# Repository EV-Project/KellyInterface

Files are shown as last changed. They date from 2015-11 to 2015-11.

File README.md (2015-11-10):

# KellyInterface
A hardware interface to link the Kelly motor controller to a CAN bus control scheme
This uses a digital Potentiometer to drive the throttle and brake signals, and BJTs to drive the microswitch inputs.

Includes a CAN and RS232 interface between the Kelly motor controller and a teensy3.2.
Also features a configurable E-stop line and hardware shutdown signal, RC charge-pump Watchdog timer, and access to the motor's hall effect outputs.

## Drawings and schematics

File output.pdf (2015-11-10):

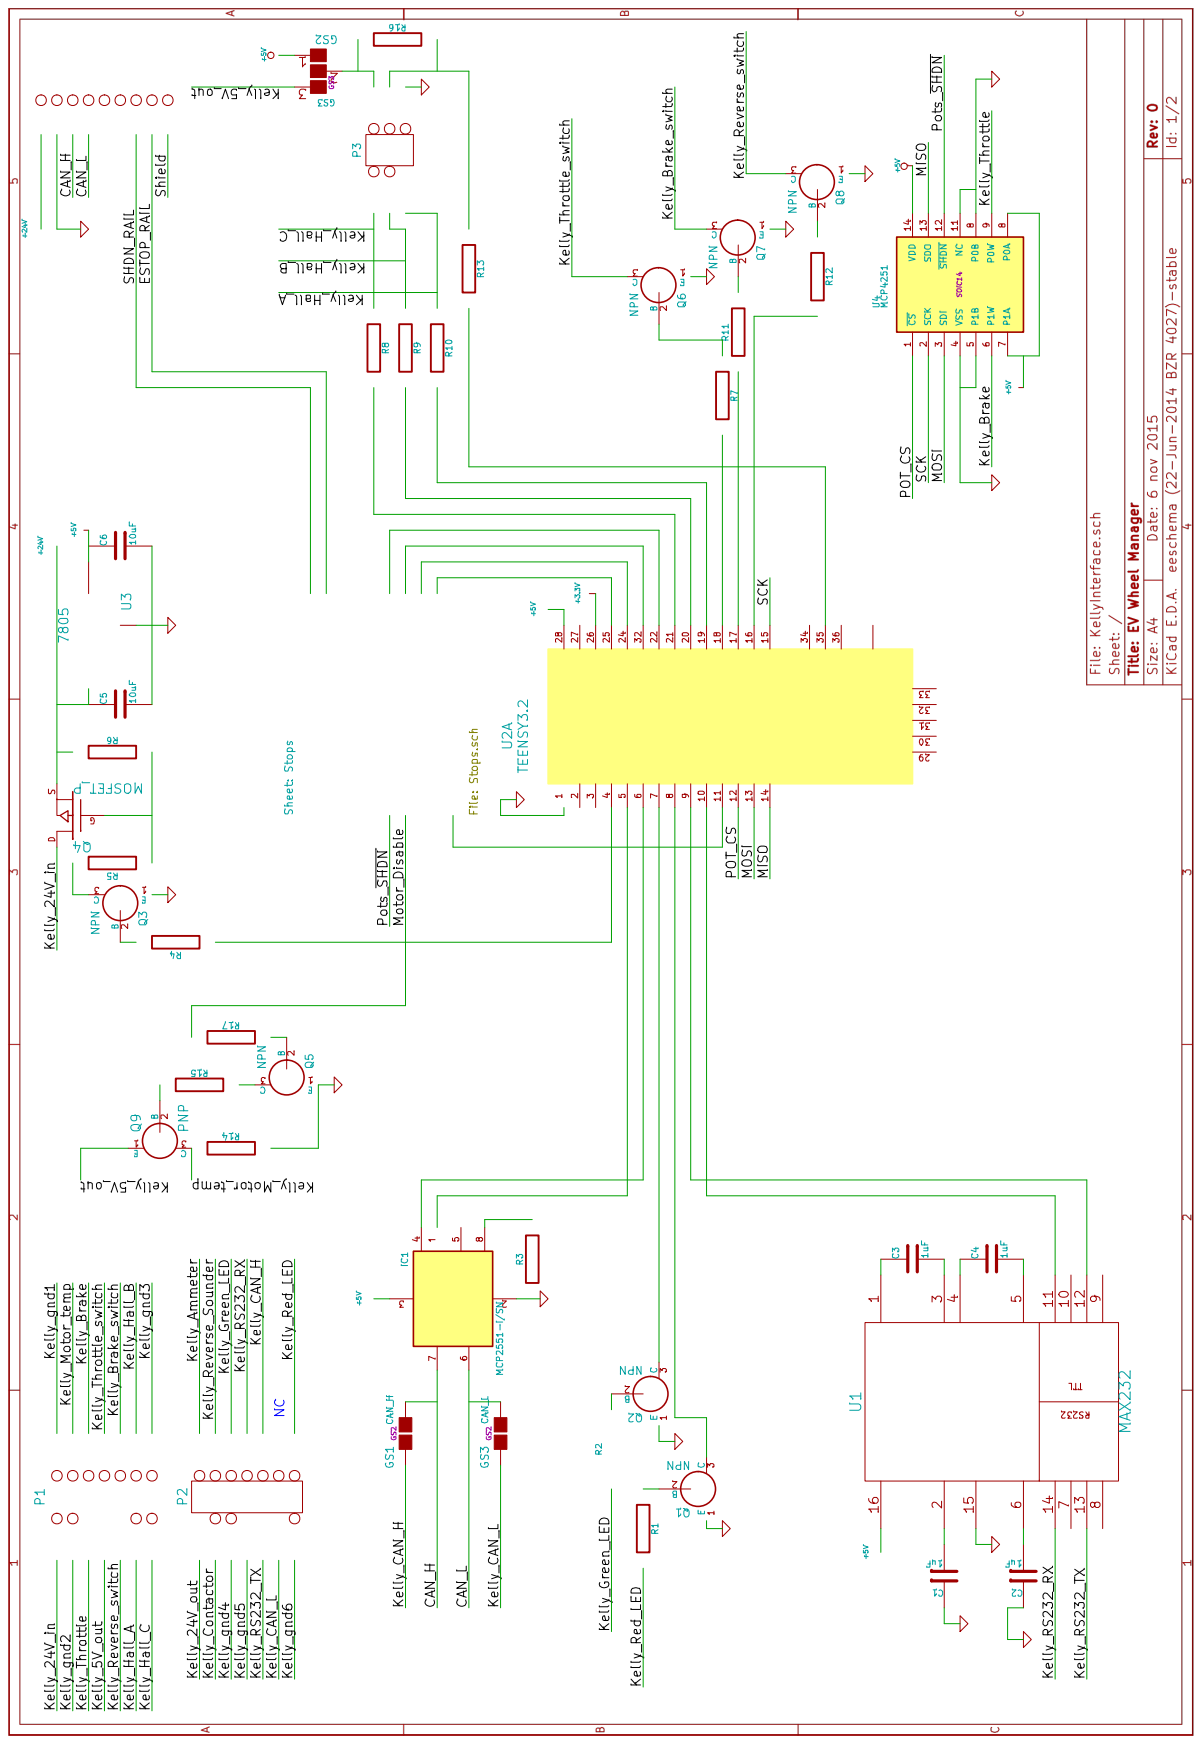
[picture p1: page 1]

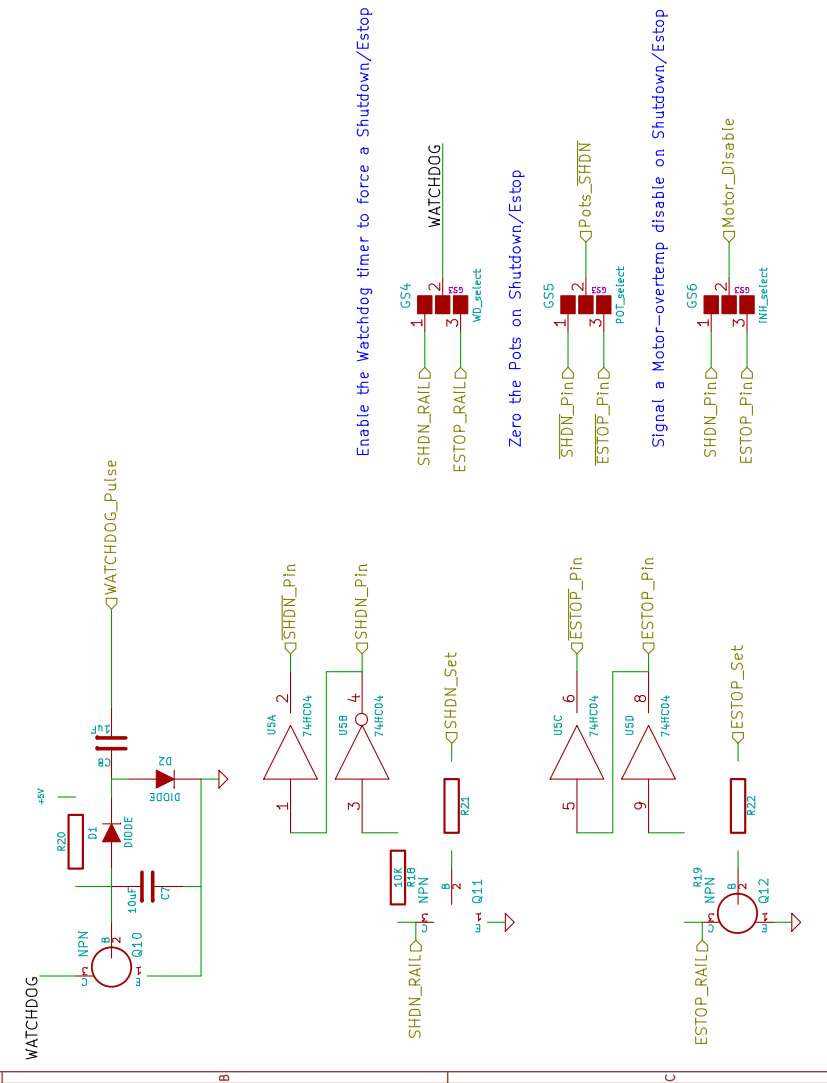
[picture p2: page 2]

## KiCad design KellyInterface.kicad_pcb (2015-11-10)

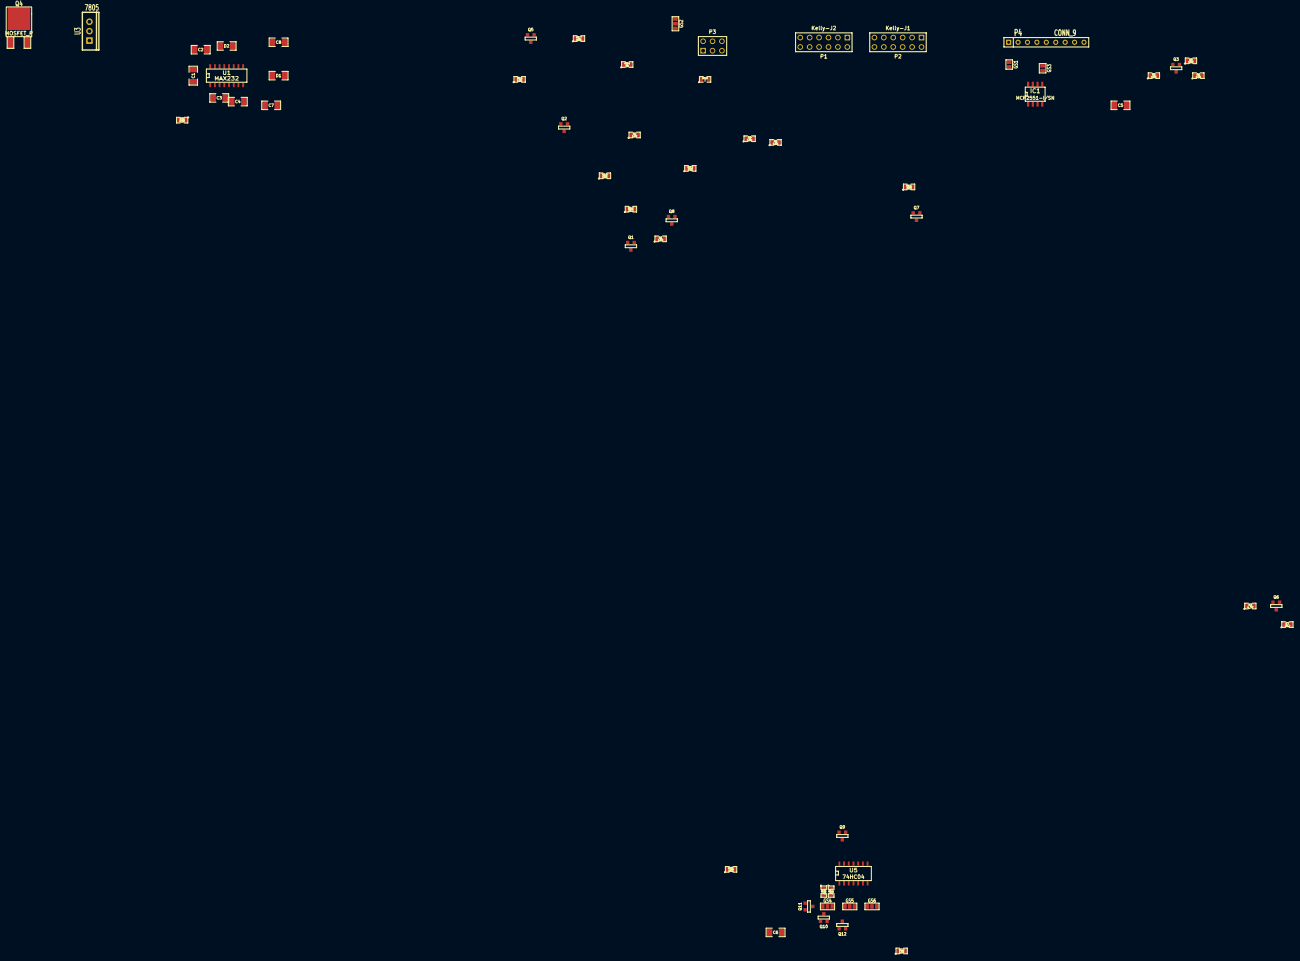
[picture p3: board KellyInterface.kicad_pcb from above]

Board: 2 copper layers, 58 parts (0 on the bottom side), 52 nets, no tracks yet.

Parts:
C1, C2, C3, C4, C8: 1uF; SM1206
C5, C6, C7: 10uF; SM1206
D1, D2: DIODE; SM1206
GS1: CAN_H; GS2
GS2: GS3
GS3: CAN_L; GS2
GS4: WD_select; GS3
GS5: POT_select; GS3
GS6: INH_select; GS3
IC1: MCP2551-I/SN; SO8E
P1: Kelly-J2; pin_array_6x2
P2: Kelly-J1; pin_array_6x2
P3: Motor_Sig; pin_array_3x2
P4: CONN_9; SIL-9
Q1, Q2, Q3, Q5, Q6, Q7, Q8, Q10, Q11, Q12: NPN; SOT23EBC
Q4: MOSFET_P; DPAK2
Q9: PNP; SOT23EBC
R1, R2, R4, R5, R6, R8, R9, R10, R13, R15, R17, R18, R19, R20, R21, R22: 10K; SM0805
R3: 4.7K; SM0805
R7, R11, R12: 2K2; SM0805
R14: 1K; SM0805
R16: -; SM0805
U1: MAX232; SO16E
U3: 7805; TO220_VERT
U5: 74HC04; SO14E

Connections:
+5V: GS2.1, IC1.3, R20.2, U1.16
+24V: C5.1, P4.1, R6.1
/CAN_H: GS1.2, IC1.7, P4.3
/CAN_L: GS3.2, IC1.6, P4.4
/Kelly_5V_out: GS2.3, P1.7, Q9.1
/Kelly_Brake_switch: P1.10, Q7.3
/Kelly_CAN_H: GS1.1, P2.10
/Kelly_CAN_L: GS3.1, P2.11
/Kelly_Green_LED: P2.6, R2.1
/Kelly_Hall_A: P1.11, P3.5, R10.1
/Kelly_Hall_B: P1.12, P3.3, R9.1
/Kelly_Hall_C: P3.1, R8.1
/Kelly_Motor_temp: P1.4, Q9.3, R14.1
/Kelly_RS232_RX: P2.8, U1.14
/Kelly_RS232_TX: P2.9, U1.13
/Kelly_Reverse_switch: P1.9, Q8.3
/Kelly_Throttle_switch: P1.8, Q6.3
/Stops/ESTOP_Pin: GS6.3, U5.5, U5.8
/Stops/ESTOP_RAIL: GS4.3, P4.8, Q12.3, R19.2
/Stops/Motor_Disable: GS6.2, R17.1
/Stops/SHDN_Pin: GS6.1, U5.1, U5.4
/Stops/SHDN_RAIL: GS4.1, P4.7, Q11.3, R18.2
/Stops/WATCHDOG: GS4.2, Q10.3
/Stops/~ESTOP~_Pin: GS5.3, U5.6
/Stops/~SHDN~_Pin: GS5.1, U5.2
GND: C1.1, C2.1, C5.2, C6.2, C7.1, D2.2, IC1.2, P3.6, P4.2, Q1.1, Q2.1, Q3.1, Q5.1, Q6.1, Q7.1, Q8.1, Q10.1, Q11.1, Q12.1, R3.1, R14.2, U1.15, U5.7
unnamed: Q6.2, R7.1
unnamed: Q1.2, R1.1
unnamed: C4.2, U1.5
unnamed: C1.2, U1.2
unnamed: C2.2, U1.6
unnamed: Q2.2, R2.2
unnamed: C3.1, U1.1
unnamed: C3.2, U1.3
unnamed: C4.1, U1.4
unnamed: Q7.2, R11.2
unnamed: Q8.2, R12.1
unnamed: R5.1, R6.2
unnamed: Q3.3, R5.2
unnamed: GS2.2, P3.2, R16.1
unnamed: P3.4, R13.1, R16.2
unnamed: Q3.2, R4.2
unnamed: Q9.2, R15.1
unnamed: Q5.3, R15.2
unnamed: Q5.2, R17.2
unnamed: IC1.8, R3.2
unnamed: R19.1, U5.9
unnamed: Q11.2, R21.2
unnamed: Q12.2, R22.2
unnamed: R18.1, U5.3
unnamed: C8.1, D1.2, D2.1
unnamed: C7.2, D1.1, Q10.2, R20.1

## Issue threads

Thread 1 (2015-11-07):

Electrical Isolation

BrettRD, 2015-11-07:
The Kelly motor controller does not feature electrical isolation between the logic lines and the traction pack.
This is a requirement of the NCOP14, and will need to be implemented on this interface board.
The CAN bus is going to be difficult to guarantee isolation on, and there is a strong argument for implementing a second bus to reduce data congestion.

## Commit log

2015-11-04 Basic Elements
    [KellyInterface.sch]
2015-11-06 moved stops to new sheet
    [KellyInterface.sch, Stops.sch]
2015-11-07 Converted to Local and Hierarchical net labels
    [KellyInterface.sch, Stops.sch]
2015-11-10 added PDF export
    [KellyInterface.kicad_pcb]
